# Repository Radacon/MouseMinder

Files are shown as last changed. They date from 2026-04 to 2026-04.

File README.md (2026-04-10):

# MouseMinder

MouseMinder is a small ATtiny10-based hardware project with a matching programming and test fixture. This repository combines the PCB design, fixture firmware, operator GUI, mechanical CAD exports, and simulation or validation data used to build and test the device.

## Repository Layout

- `codebase/`
  - Arduino Uno fixture firmware in `ardu_tiny_toaster.ino`
  - Base TPI programmer implementation in `tiny10_base_code.ino`
  - Operator desktop GUI in `gui.py`
  - Early or alternate device firmware work under `AtmelStudio/`
- `pcb_design/`
  - Main MouseMinder KiCad project files:
    - `MouseMinder.kicad_sch`
    - `MouseMinder.kicad_pcb`
    - `MouseMinder.kicad_pro`
  - Fixture or shield PCB design under `MouseMinder_Programmer_Shield/`
  - Archived KiCad backups under `MouseMinder-backups/`
  - Older release archives under `mouseminder_prev_versions/`
- `mechanical_design/`
  - Enclosure and trap body STEP exports under `trap_body/`
  - Accessory parts such as the battery isolator under `accessories/`
- `sim_and_test/`
  - Power profiling captures under `PowerProfilerData/`
  - Simulation exports under `Simulation/`

## Hardware Overview

The main board centers on an `ATtiny10-TS` and includes:

- A coin-cell battery holder
- A buzzer
- An LED indicator
- Two pushbuttons
- A discrete power or latching section around `Q1`

The repository also includes a separate programmer shield design and a fixture workflow for flashing and validating boards during bring-up or production.

## PCB Design Files

Primary electrical design assets live in `pcb_design/`:

- `MouseMinder.kicad_sch`
- `MouseMinder.kicad_pcb`
- `MouseMinder.kicad_pro`

Related hardware history is split out into:

- `pcb_design/MouseMinder_Programmer_Shield/` for the programming fixture PCB
- `pcb_design/MouseMinder-backups/` for KiCad backup archives
- `pcb_design/mouseminder_prev_versions/` for older packaged revisions

## Firmware And GUI

The programming and test fixture is built around an Arduino Uno and a Python desktop GUI.

Arduino-side files in `codebase/`:

- `ardu_tiny_toaster.ino`: fixture control firmware
- `tiny10_base_code.ino`: base TPI programming support for ATtiny4/5/9/10/20/40 devices

Desktop-side files in `codebase/`:

- `gui.py`: operator GUI for selecting firmware, discovering the fixture over serial, and running the programming loop
- `requirements.txt`: original behavior notes for the GUI and fixture

There is also an Atmel Studio project under `codebase/AtmelStudio/MouseMinder/` with a `main.c` firmware entry point and generated debug outputs.

## Fixture I/O Mapping

The current fixture firmware uses:

- `D10` -> `!RST`
- `D11/D12` -> `TPIDATA`
- `D13` -> `TPICLK`
- `A0` -> `BATT`
- `A1` -> `LATCHED`

The operator GUI is intended to:

- Auto-discover the Arduino fixture over available COM ports
- Show connection and pin-state information
- Let the operator select a `.hex` file
- Run the detect, program, verify, and test loop

## Mechanical Assets

Mechanical CAD exports are grouped under `mechanical_design/`:

- `trap_body/` contains enclosure and body STEP files, including lid and clip geometry
- `accessories/` contains supporting parts such as `Battery_Isolator_debossed.STEP`

## Simulation And Validation Data

Supporting measurement and simulation files live in `sim_and_test/`:

- `PowerProfilerData/` contains sleep-current or power measurement CSV files
- `Simulation/` contains scope and waveform export data from circuit simulation work

## Typical Workflow

1. Open the main hardware in `pcb_design/MouseMinder.kicad_sch` and `pcb_design/MouseMinder.kicad_pcb`.
2. Load the Arduino fixture firmware from `codebase/ardu_tiny_toaster.ino`.
3. Launch the operator GUI from `codebase/gui.py`.
4. Connect the programming fixture and target board.
5. Select a target `.hex` file and run the programming and test cycle.

## Running The GUI

Install the required Python package, then launch the GUI:

```powershell
pip install pyserial
python codebase\gui.py
```

The GUI depends on:

- `pyserial`
- Python standard library `tkinter`

## Fastest Entry Points

If you are picking up the project fresh, start with:

- `pcb_design/MouseMinder.kicad_sch`
- `pcb_design/MouseMinder.kicad_pcb`
- `codebase/ardu_tiny_toaster.ino`
- `codebase/gui.py`

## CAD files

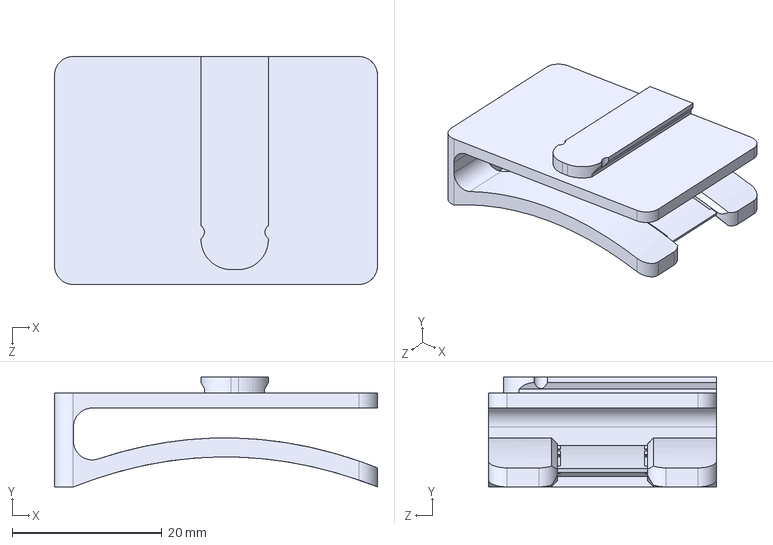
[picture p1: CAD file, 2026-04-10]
mechanical_design/accessories/clip.STEP
43.2 x 14.7 x 30.5 mm

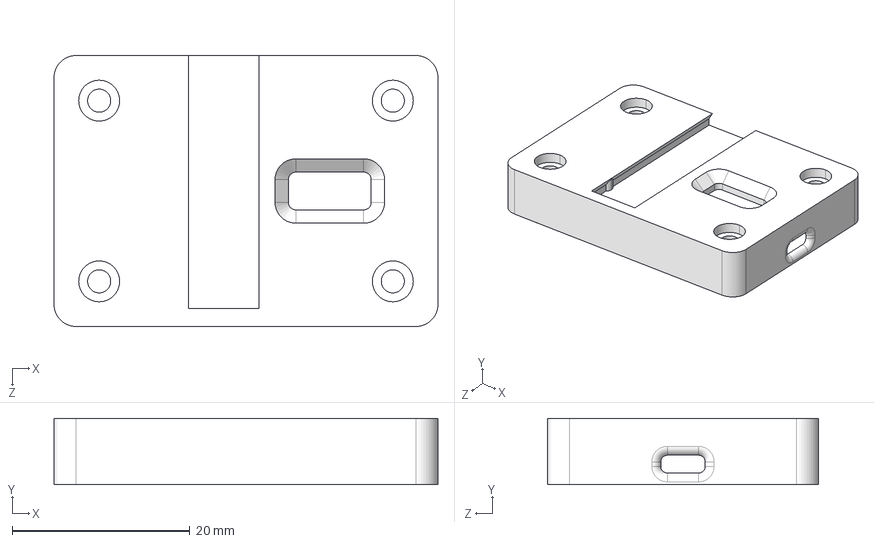
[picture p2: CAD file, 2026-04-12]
mechanical_design/trap_body/006_Trapside.step
43.2 x 7.44 x 30.5 mm

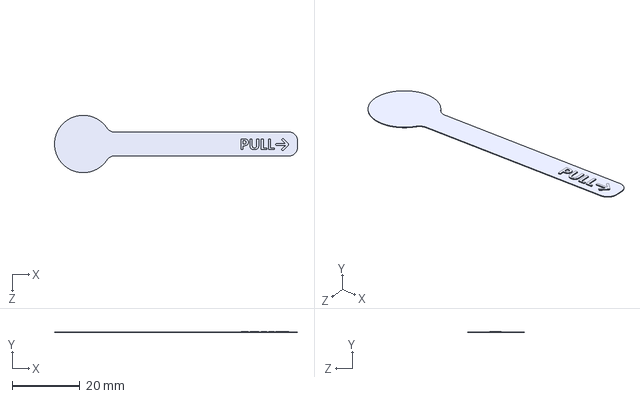
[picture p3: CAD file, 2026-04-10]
mechanical_design/accessories/Battery_Isolator_debossed.STEP
72.0 x 0.36 x 17.0 mm

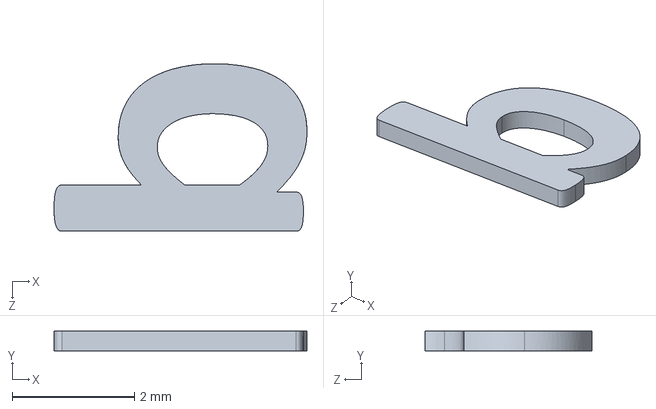
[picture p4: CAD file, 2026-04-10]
mechanical_design/trap_body/000_Boss-Extrude11[15].step
4.14 x 0.32 x 2.74 mm

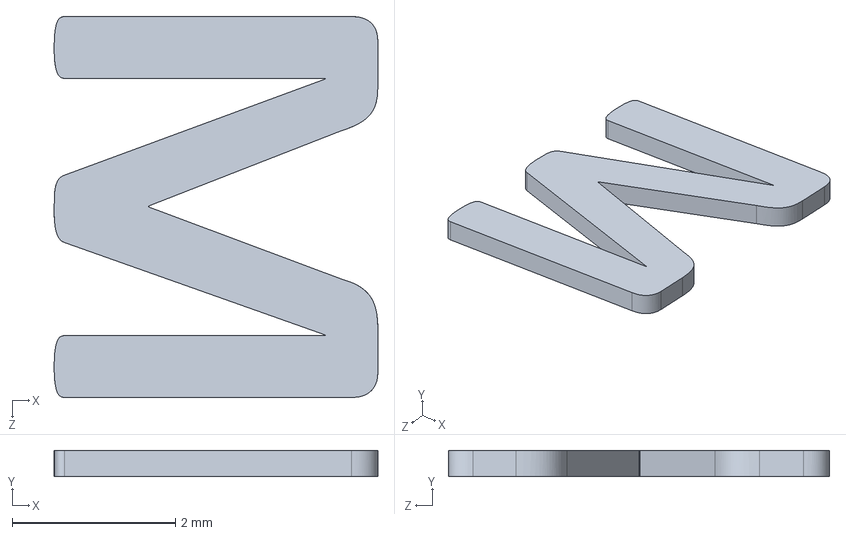
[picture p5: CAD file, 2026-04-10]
mechanical_design/trap_body/017_Boss-Extrude11[7].step
3.97 x 0.32 x 4.67 mm

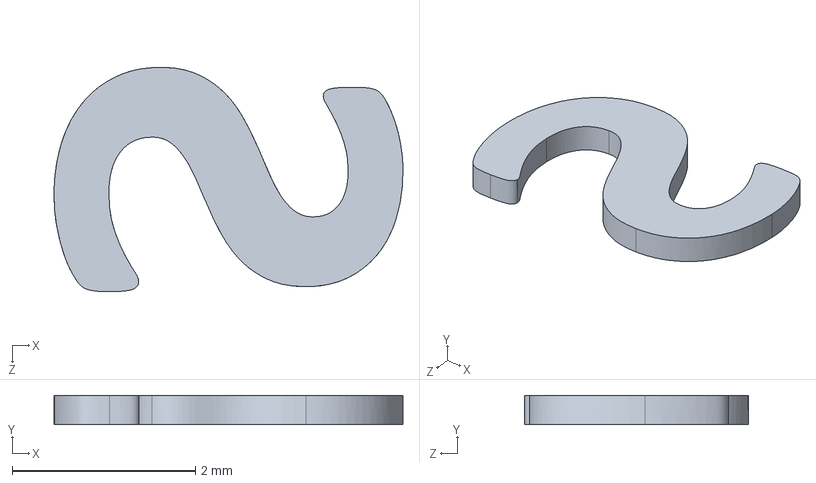
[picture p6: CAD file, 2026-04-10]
mechanical_design/trap_body/018_Boss-Extrude11[2].step
3.81 x 0.32 x 2.45 mm

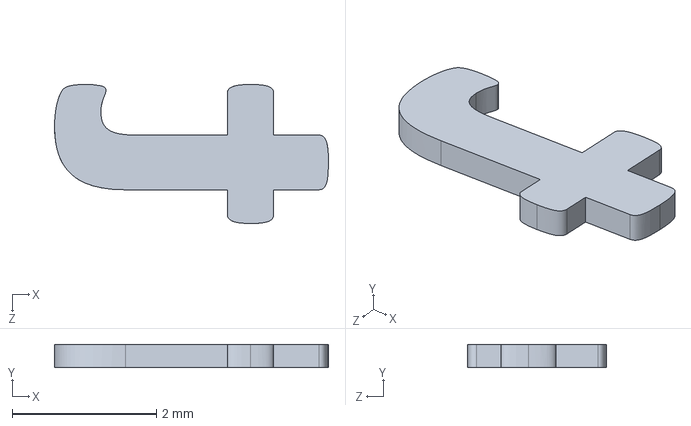
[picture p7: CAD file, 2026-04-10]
mechanical_design/trap_body/007_Boss-Extrude11[12].step
3.79 x 0.32 x 1.93 mm

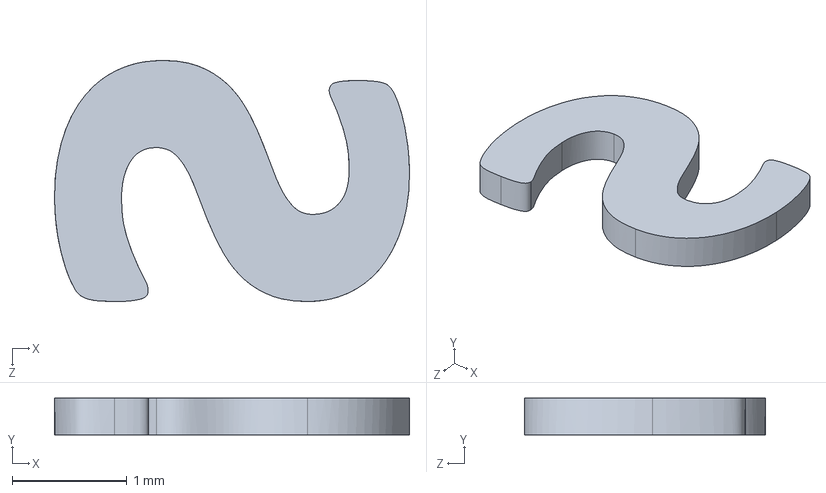
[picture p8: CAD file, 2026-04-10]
mechanical_design/trap_body/010_Boss-Extrude11[18].step
3.09 x 0.32 x 2.10 mm

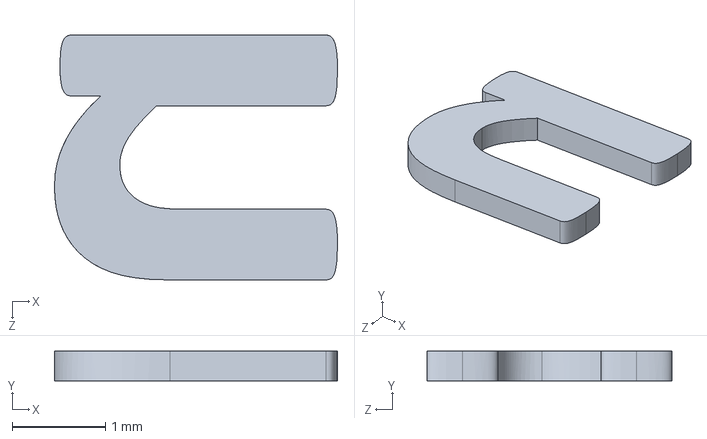
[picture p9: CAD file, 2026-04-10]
mechanical_design/trap_body/014_Boss-Extrude11[9].step
3.03 x 0.32 x 2.63 mm

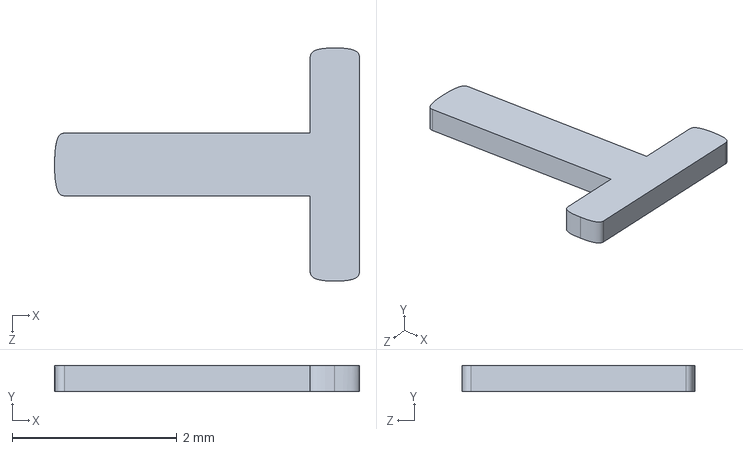
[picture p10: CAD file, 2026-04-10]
mechanical_design/trap_body/021_Boss-Extrude11[6].step
3.70 x 0.32 x 2.83 mm

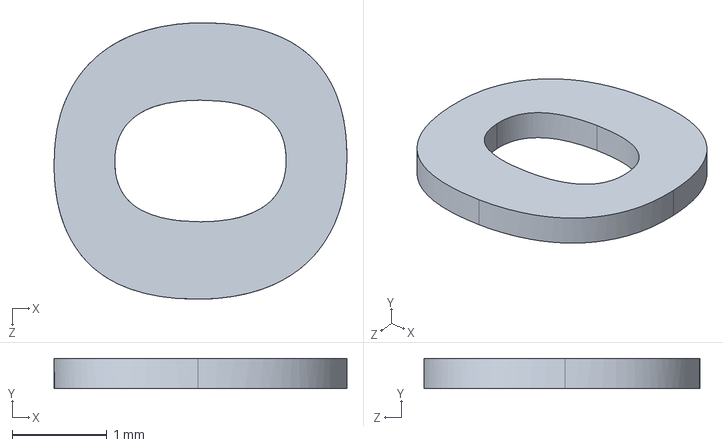
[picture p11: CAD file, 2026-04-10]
mechanical_design/trap_body/020_Boss-Extrude11[17].step
3.09 x 0.32 x 2.92 mm

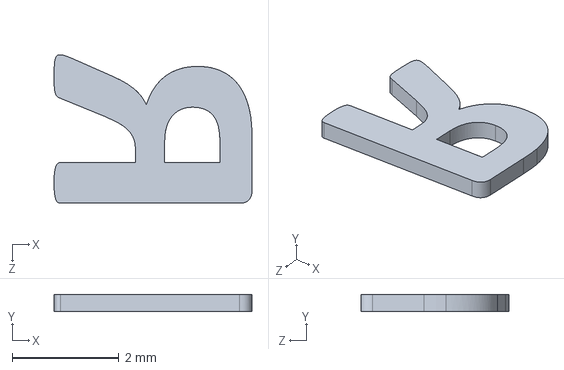
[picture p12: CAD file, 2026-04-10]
mechanical_design/trap_body/004_Boss-Extrude11[1].step
3.70 x 0.32 x 2.78 mm

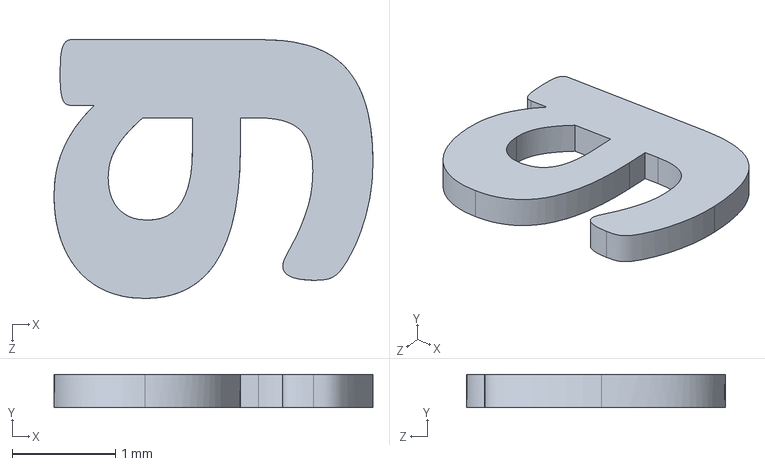
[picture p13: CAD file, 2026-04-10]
mechanical_design/trap_body/002_Boss-Extrude11[14].step
3.09 x 0.32 x 2.51 mm

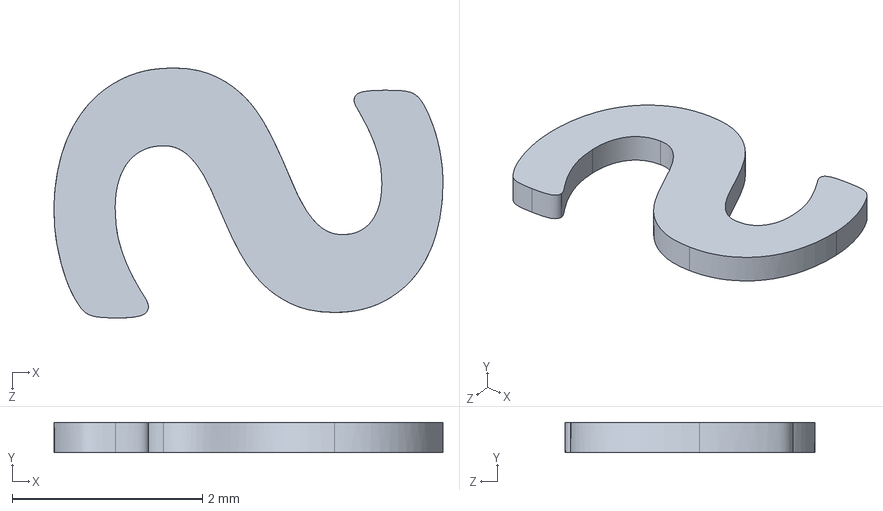
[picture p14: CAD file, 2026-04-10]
mechanical_design/trap_body/009_Boss-Extrude11[21].step
4.09 x 0.32 x 2.63 mm

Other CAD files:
mechanical_design/trap_body/005_Boss-Extrude11[13].step
mechanical_design/trap_body/003_Boss-Extrude11[8].step
mechanical_design/trap_body/011_Boss-Extrude11[16].step
mechanical_design/trap_body/022_Boss-Extrude11[5].step
mechanical_design/trap_body/001_Boss-Extrude11[4].step
mechanical_design/trap_body/008_Lid.step
mechanical_design/trap_body/012_Boss-Extrude11[10].step
mechanical_design/trap_body/013_Boss-Extrude11[11].step
mechanical_design/trap_body/015_Boss-Extrude11[3].step
mechanical_design/trap_body/016_Boss-Extrude11[20].step
mechanical_design/trap_body/019_Boss-Extrude11[19].step

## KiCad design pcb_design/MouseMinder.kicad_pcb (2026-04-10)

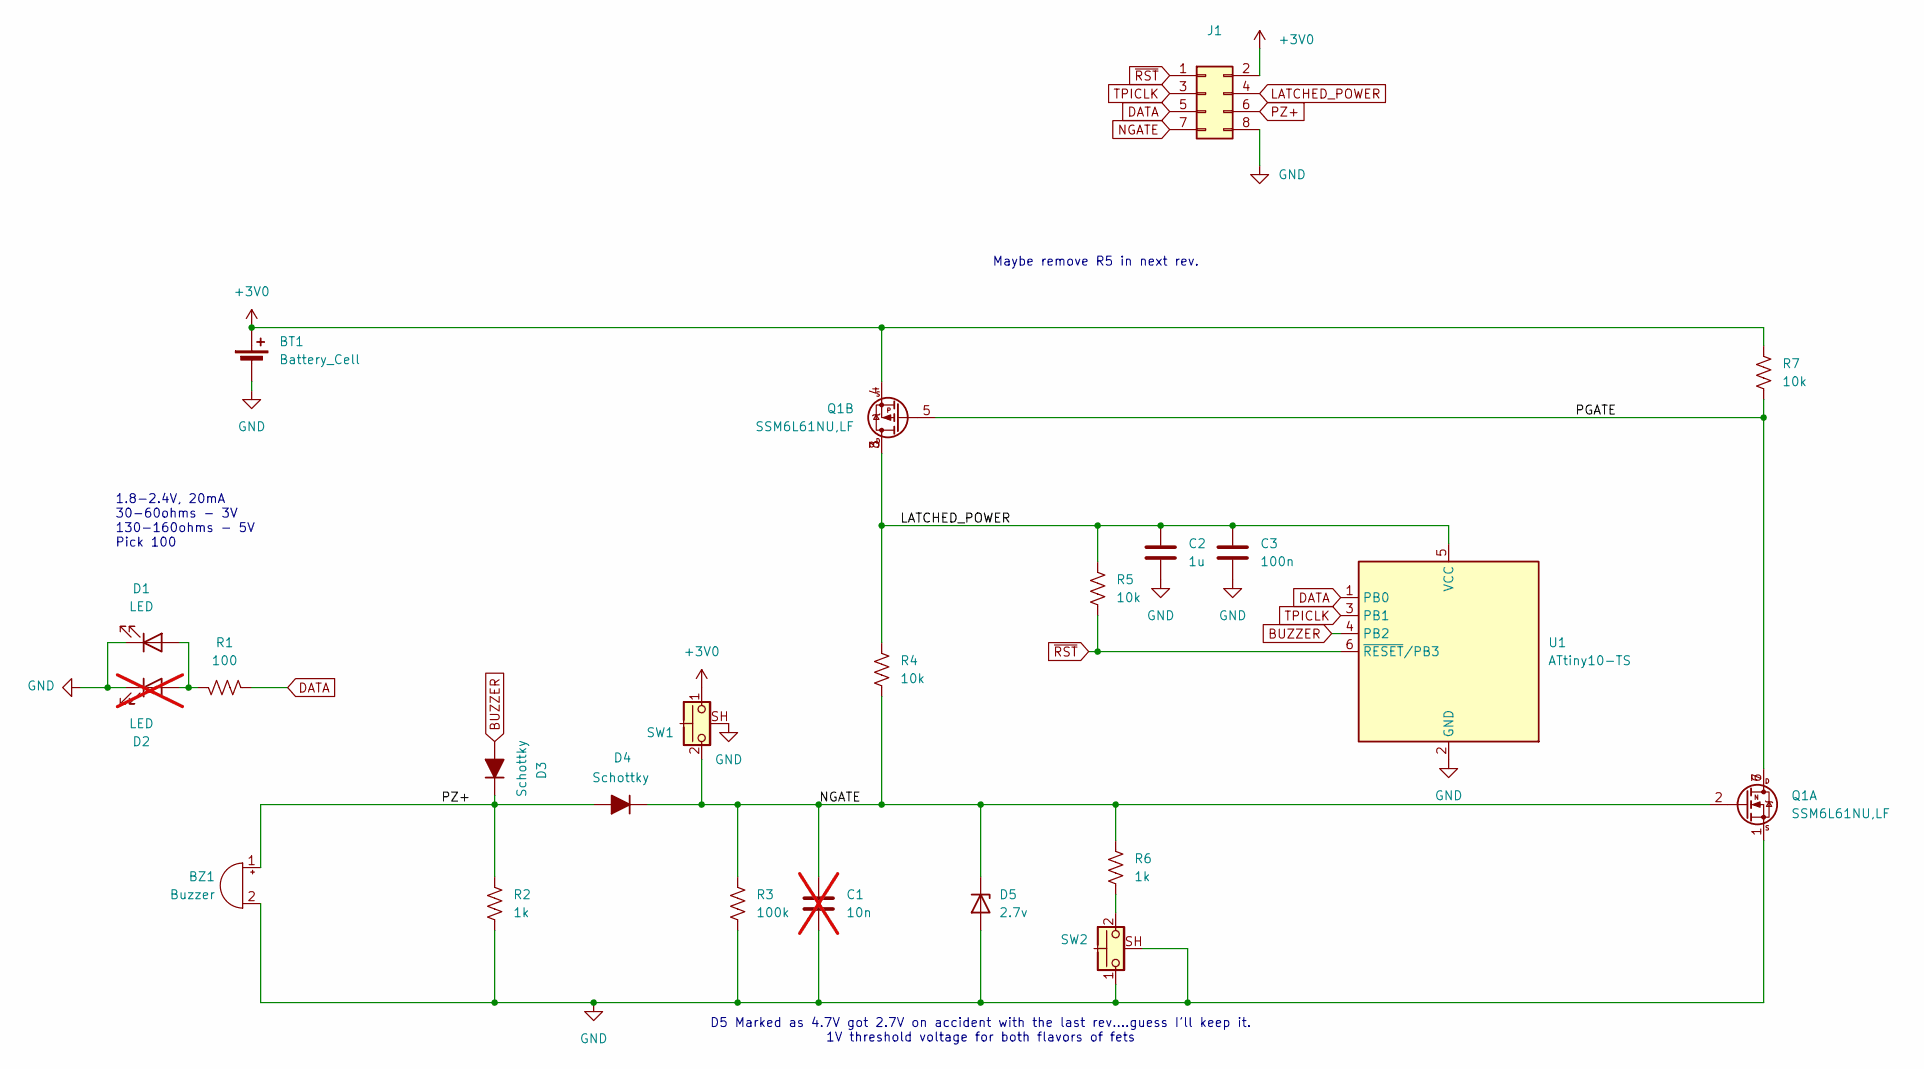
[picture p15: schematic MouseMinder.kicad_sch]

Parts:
BT1: Battery_Cell; MY-2032-08; MPN MY-2032-08; JLC_MPN C964831
BZ1: Buzzer; GSC1230YB-3V4000; MPN GSC1230YB-3V4000; JLC_MPN C255333
C1: 10n; C_0402_1005Metric; not fitted
C2: 1u; C_0402_1005Metric; MPN CL05A105KP5NNNC; JLC_MPN C14445
C3: 100n; C_0402_1005Metric; MPN 0402F104M500NT; JLC_MPN C1581
D1: LED; XL-2810UYC; MPN XL-2810UYC; JLC_MPN C3646949
D2: LED; LED_0805_2012Metric; MPN APTD2012LSURCK; JLC_MPN C5355441; not fitted
D3, D4: Schottky; D_0603_1608Metric; MPN CD0603-B0240R; JLC_MPN C3312582
D5: 2.7v; D_0603_1608Metric; MPN CZRU52C2V7-HF; JLC_MPN C2886070
J1: Conn_02x04_Odd_Even; PinHeader_2x04_P2.54mm_Vertical
Q1: SSM6L61NU,LF; SON65P200X200X80-8N; MPN DMC1229UFDB-7; JLC_MPN C443653
R1: 100; R_0402_1005Metric; MPN 0402WGF1000TCE; JLC_MPN C25076
R2, R6: 1k; R_0402_1005Metric; MPN 0402WGF1001TCE; JLC_MPN C11702
R3: 100k; R_0402_1005Metric; MPN 0402WGF1003TCE; JLC_MPN C25741
R4, R5, R7: 10k; R_0402_1005Metric; MPN RCA0210KJLF; JLC_MPN C22356213
SW1, SW2: SW_Push_Shielded; SW_Push_1P1T-SH_NO_CK_KMR2xxG; MPN KMR221GLFS; JLC_MPN C72443
U1: ATtiny10-TS; SOT-23-6; MPN ATTINY10-TSHR; JLC_MPN C128438

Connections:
+3V0: BT1.1 (+), J1.2, Q1.4 (SP), R7.1, SW1.1
/PGATE: Q1.5 (GP), Q1.6 (DN), Q1.7 (DN), R7.2
BUZZER: D3.2 (A), U1.4 (PB2)
DATA: J1.5, R1.1, U1.1 (PB0)
GND: BT1.2 (-), BZ1.2 (-), C1.2, C2.2, C3.2, D1.1 (K), D2.1 (K), D5.2 (A), J1.8, Q1.1 (SN), R2.2, R3.2, SW1.SH (B), SW2.1, SW2.SH (B), U1.2 (GND)
LATCHED_POWER: C2.1, C3.1, J1.4, Q1.3 (DP), Q1.8 (DP), R4.1, R5.1, U1.5 (VCC)
NGATE: C1.1, D4.1 (K), D5.1 (K), J1.7, Q1.2 (GN), R3.1, R4.2, R6.1, SW1.2
unnamed: D1.2 (A), D2.2 (A), R1.2
unnamed: R6.2, SW2.2
PZ+: BZ1.1 (+), D3.1 (K), D4.2 (A), J1.6, R2.1
TPICLK: J1.3, U1.3 (PB1)
~RST: J1.1, R5.2, U1.6 (~RESET/PB3)

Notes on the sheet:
1.8-2.4V, 20mA 30-60ohms - 3V 130-160ohms - 5V Pick 100
Maybe remove R5 in next rev.
D5 Marked as 4.7V got 2.7V on accident with the last rev....guess I'll keep it. 1V threshold voltage for both flavors of fets

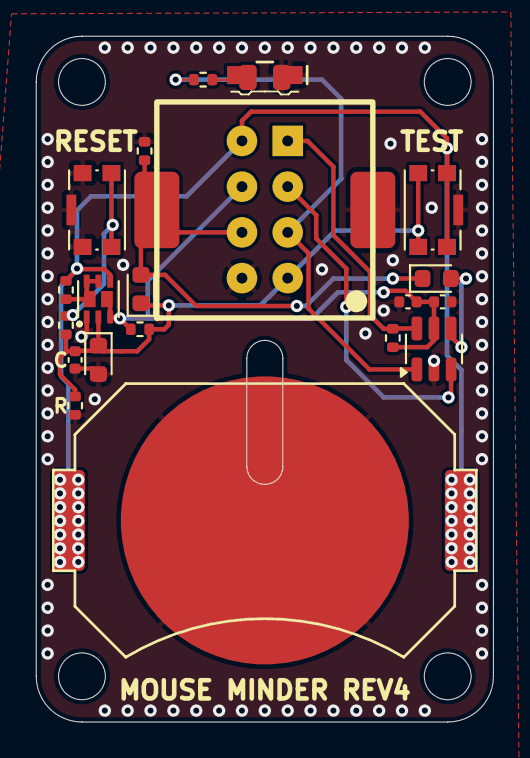
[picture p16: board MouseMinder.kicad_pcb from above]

Board: 2 copper layers, 25.4 x 38.1 mm, 22 parts (1 on the bottom side), 12 nets.

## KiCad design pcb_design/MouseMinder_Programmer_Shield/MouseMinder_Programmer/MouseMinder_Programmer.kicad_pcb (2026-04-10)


Board: 2 copper layers, 68.6 x 53.3 mm, 8 parts (0 on the bottom side), 3 nets, no tracks yet.

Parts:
J1: Power; PinSocket_1x08_P2.54mm_Vertical
J2: Digital/PWM; PinSocket_1x10_P2.54mm_Vertical
J3: Analog; PinSocket_1x06_P2.54mm_Vertical
J4: Digital/PWM; PinSocket_1x08_P2.54mm_Vertical
MH1, MH2, MH3, MH4: MountingHole_3.2mm

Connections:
/SCL/A5: J2.1, J3.6
/SDA/A4: J2.2, J3.5
GND: J1.6, J1.7, J2.4

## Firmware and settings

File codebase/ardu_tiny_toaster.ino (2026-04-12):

#include <SPI.h>
#include "pins_arduino.h"

#define SLD    0x20
#define SLDp   0x24
#define SSTp   0x64
#define SSTPRH 0x69
#define SSTPRL 0x68
#define SKEY   0xE0
#define NVM_PROGRAM_ENABLE 0x1289AB45CDD888FFULL

#define NVMCMD 0x33
#define NVMCSR 0x32
#define NVM_NOP 0x00
#define NVM_CHIP_ERASE 0x10
#define NVM_WORD_WRITE 0x1D

#define PIN_RESET 10
#define PIN_TPIDATA_MOSI 11
#define PIN_TPIDATA_MISO 12
#define PIN_TPICLK 13
#define PIN_BATT A0
#define PIN_LATCHED A1

#define Tiny4_5 10
#define Tiny9 1
#define Tiny10 1
#define Tiny20 2
#define Tiny40 4

#define TimeOut 1
#define HexError 2
#define TooLarge 3
#define MAX_VERIFY_FLASH_BYTES 1024
#define BATT_FAIL_THRESHOLD_MV 2000
#define SERIAL_BAUDRATE 115200

enum ToasterState {
  STATE_WAIT_GUI,
  STATE_WAIT_TEST_BUTTON,
  STATE_WAIT_RESET_BUTTON,
  STATE_WAIT_TEST_CONFIRM,
  STATE_SCAN_DEVICE,
  STATE_WAIT_HEX,
  STATE_WAIT_BATT_CLEAR
};

enum PinRoleMode {
  ROLE_INPUT,
  ROLE_OUTPUT,
  ROLE_ADC
};

unsigned short adrs = 0x0000;
uint8_t data[16];
uint8_t expectedImage[MAX_VERIFY_FLASH_BYTES];
unsigned int progSize = 0;
unsigned int expectedImageSize = 0;
bool expectedImageValid = false;

int timeout;
uint8_t b, b1, b2, b3;
char type = 0;

ToasterState state = STATE_WAIT_GUI;
bool guiConnected = false;
bool hexRequested = false;
bool actionRequested = false;
bool programPrepared = false;
bool lastDeviceValid = false;
bool tpiTimedOut = false;
size_t serialLineIndex = 0;
unsigned long lastHelloAt = 0;
unsigned long lastScanAt = 0;
unsigned long lastPinReportAt = 0;
unsigned long battClearSince = 0;
unsigned long latchedHighSince = 0;
unsigned long latchedLowSince = 0;
unsigned long stateChangedAt = 0;

PinRoleMode battMode = ROLE_OUTPUT;
PinRoleMode latchedMode = ROLE_OUTPUT;
int battOutputValue = LOW;
int latchedOutputValue = LOW;

uint8_t lastId1 = 0;
uint8_t lastId2 = 0;
uint8_t lastId3 = 0;

void setState(ToasterState nextState, const __FlashStringHelper *message);
void emitHello();
void emitLog(const __FlashStringHelper *message);
void emitResult(const __FlashStringHelper *code, long detail = -1);
void emitDevice(bool valid);
void emitPins();
void emitPinBatt();
void emitPinLatched();
const __FlashStringHelper *stateName(ToasterState value);
const __FlashStringHelper *deviceNameFromId(uint8_t id1, uint8_t id2, uint8_t id3);
void configureForScan();
void configureForWaitButton();
void resetForNextDevice();
void emitRawDeviceId();
void setProgrammingPinsHighImpedance();
void setBattOutput(int value);
void setBattAdc();
void setLatchedOutput(int value);
void setLatchedAdc();
int readBattMillivolts();
int readLatchedMillivolts();
int sampleBattAverageMillivolts(unsigned long durationMs);
bool latchedIsHigh();
bool latchedIsStableHigh();
void resetSerialLineReader();
bool readSerialLine(char *buffer, size_t length);
void handleCommand(const char *line);
void processStateMachine();
void processScanDevice();
void processWaitHex();
bool runProgrammingCycle();
bool beginProgrammingSession();
bool runClearCycle();
bool runMetadataReadCycle();
void completeClearRequest();
void completeMetadataReadRequest();
bool start_tpi();
void finish();
bool readDeviceIdentity(uint8_t &id1, uint8_t &id2, uint8_t &id3);
bool detectConnectedDevice();
boolean writeProgramFromSerial();
bool waitForNvmReady(unsigned long timeoutMs);
unsigned int flashByteLength();
bool supportsFlashVerify();
void resetExpectedImage();
bool storeExpectedByte(unsigned int address, uint8_t value);
bool dumpAndVerifyBlankFlash();
bool verifyWrittenFlash();
void dumpFlashWindow(unsigned int flashBytes);
bool readFlashByteAt(unsigned int flashOffset, uint8_t &value);
bool readFlashPage(unsigned int flashOffset, uint8_t *buffer, uint8_t count);
bool pageMatchesMetadata(const uint8_t *buffer, const char *text);
void emitMetadataField(const __FlashStringHelper *key, const uint8_t *buffer, uint8_t count);
bool latchedIsLow();
bool latchedIsStableLow();
int readHexChar();
void discardToLineEnd();
bool eraseChip();
void ERROR_data(char i);
void tpi_send_byte(uint8_t dataByte);
uint8_t tpi_receive_byte(void);
void send_skey(uint64_t nvm_key);
void setPointer(unsigned short address);
void writeIO(uint8_t address, uint8_t value);
uint8_t readIO(uint8_t address);
void writeCSS(uint8_t address, uint8_t value);
uint8_t readCSS(uint8_t address);
uint8_t byteval(char c1, char c2);
void outHex(unsigned int n, char l);

void setup() {
  Serial.begin(SERIAL_BAUDRATE);
  timeout = 20000;
  setProgrammingPinsHighImpedance();
  configureForScan();
  setState(STATE_WAIT_GUI, F("WAITING_FOR_GUI"));
}

void loop() {
  if (!guiConnected && millis() - lastHelloAt >= 500) {
    emitHello();
    lastHelloAt = millis();
  }

  if (state == STATE_WAIT_HEX) {
    processWaitHex();
  } else {
    char line[96];
    if (readSerialLine(line, sizeof(line))) {
      handleCommand(line);
    }
  }

  if (guiConnected) {
    processStateMachine();
  }

  if (state != STATE_WAIT_HEX && millis() - lastPinReportAt >= 250) {
    emitPins();
    lastPinReportAt = millis();
  }
}

void setState(ToasterState nextState, const __FlashStringHelper *message) {
  ToasterState previous = state;
  state = nextState;
  resetSerialLineReader();
  stateChangedAt = millis();
  Serial.print(F("LOG STATE_"));
  Serial.print(stateName(previous));
  Serial.print(F("_TO_"));
  Serial.println(stateName(nextState));
  Serial.print(F("STATUS "));
  Serial.print(stateName(nextState));
  Serial.print(F(" "));
  Serial.println(message);
}

const __FlashStringHelper *stateName(ToasterState value) {
  switch (value) {
    case STATE_WAIT_GUI: return F("WAIT_GUI");
    case STATE_WAIT_TEST_BUTTON: return F("WAIT_TEST_BUTTON");
    case STATE_WAIT_RESET_BUTTON: return F("WAIT_RESET_BUTTON");
    case STATE_WAIT_TEST_CONFIRM: return F("WAIT_TEST_CONFIRM");
    case STATE_SCAN_DEVICE: return F("SCAN_DEVICE");
    case STATE_WAIT_HEX: return F("WAIT_HEX");
    case STATE_WAIT_BATT_CLEAR: return F("WAIT_BATT_CLEAR");
    default: return F("UNKNOWN");
  }
}

void emitHello() {
  Serial.println(F("HELLO ARDUINO_TOASTER"));
}

void emitLog(const __FlashStringHelper *message) {
  Serial.print(F("LOG "));
  Serial.println(message);
}

void emitResult(const __FlashStringHelper *code, long detail) {
  Serial.print(F("RESULT "));
  Serial.print(code);
  if (detail >= 0) {
    Serial.print(F(" "));
    Serial.println(detail);
    return;
  }
  Serial.println();
}

const __FlashStringHelper *deviceNameFromId(uint8_t id1, uint8_t id2, uint8_t id3) {
  if (id1 == 0x1E && id2 == 0x8F && id3 == 0x0A) {
    return F("ATtiny4");
  }
  if (id1 == 0x1E && id2 == 0x8F && id3 == 0x09) {
    return F("ATtiny5");
  }
  if (id1 == 0x1E && id2 == 0x90 && id3 == 0x08) {
    return F("ATtiny9");
  }
  if (id1 == 0x1E && id2 == 0x90 && id3 == 0x03) {
    return F("ATtiny10");
  }
  if (id1 == 0x1E && id2 == 0x91 && id3 == 0x0F) {
    return F("ATtiny20");
  }
  if (id1 == 0x1E && id2 == 0x92 && id3 == 0x0E) {
    return F("ATtiny40");
  }
  return F("UNKNOWN");
}

void emitDevice(bool valid) {
  Serial.print(F("DEVICE "));
  Serial.print(valid ? F("VALID ") : F("INVALID "));
  Serial.print(valid ? deviceNameFromId(lastId1, lastId2, lastId3) : F("UNKNOWN"));
  Serial.print(F(" "));
  outHex(lastId1, 2);
  outHex(lastId2, 2);
  outHex(lastId3, 2);
  Serial.println();
}

void emitRawDeviceId() {
  Serial.print(F("LOG RAW_ID_"));
  outHex(lastId1, 2);
  Serial.print(F("_"));
  outHex(lastId2, 2);
  Serial.print(F("_"));
  outHex(lastId3, 2);
  Serial.println();
}

void emitPins() {
  emitPinBatt();
  emitPinLatched();
}

void emitPinBatt() {
  Serial.print(F("PIN BATT "));
  if (battMode == ROLE_OUTPUT) {
    Serial.print(F("OUT "));
    Serial.println(battOutputValue == HIGH ? F("HIGH") : F("LOW"));
    return;
  }
  if (battMode == ROLE_ADC) {
    Serial.print(F("ADC "));
    Serial.print(readBattMillivolts());
    Serial.println(F("mV"));
    return;
  }
  Serial.print(F("IN "));
  Serial.println(digitalRead(PIN_BATT) == HIGH ? F("HIGH") : F("LOW"));
}

void emitPinLatched() {
  Serial.print(F("PIN LATCHED "));
  if (latchedMode == ROLE_OUTPUT) {
    Serial.print(F("OUT "));
    Serial.println(latchedOutputValue == HIGH ? F("HIGH") : F("LOW"));
    return;
  }
  if (latchedMode == ROLE_ADC) {
    Serial.print(F("ADC "));
    Serial.print(readLatchedMillivolts());
    Serial.println(F("mV"));
    return;
  }
  Serial.print(F("IN "));
  Serial.println(latchedIsHigh() ? F("HIGH") : F("LOW"));
}

void configureForScan() {
  setProgrammingPinsHighImpedance();
  setBattOutput(HIGH);
  setLatchedAdc();
  battClearSince = 0;
}

void configureForWaitButton() {
  configureForScan();
}

void resetForNextDevice() {
  hexRequested = false;
  actionRequested = false;
  programPrepared = false;
  resetSerialLineReader();
  latchedHighSince = 0;
  latchedLowSince = 0;
  battClearSince = 0;
  lastDeviceValid = false;
  emitDevice(false);
  configureForWaitButton();
  setState(STATE_WAIT_TEST_BUTTON, F("PRESS_TEST"));
}

void setProgrammingPinsHighImpedance() {
  SPI.end();

  pinMode(PIN_RESET, INPUT);
  digitalWrite(PIN_RESET, LOW);

  pinMode(PIN_TPIDATA_MOSI, INPUT);
  digitalWrite(PIN_TPIDATA_MOSI, LOW);

  pinMode(PIN_TPIDATA_MISO, INPUT);
  digitalWrite(PIN_TPIDATA_MISO, LOW);

  pinMode(PIN_TPICLK, INPUT);
  digitalWrite(PIN_TPICLK, LOW);
}

void setBattOutput(int value) {
  pinMode(PIN_BATT, OUTPUT);
  digitalWrite(PIN_BATT, value);
  battMode = ROLE_OUTPUT;
  battOutputValue = value;
}

void setBattAdc() {
  pinMode(PIN_BATT, INPUT);
  battMode = ROLE_ADC;
}

void setLatchedOutput(int value) {
  pinMode(PIN_LATCHED, OUTPUT);
  digitalWrite(PIN_LATCHED, value);
  latchedMode = ROLE_OUTPUT;
  latchedOutputValue = value;
}

void setLatchedAdc() {
  pinMode(PIN_LATCHED, INPUT);
  latchedMode = ROLE_ADC;
}

int readBattMillivolts() {
  long sample = analogRead(PIN_BATT);
  return (int)((sample * 5000L) / 1023L);
}

int readLatchedMillivolts() {
  long sample = analogRead(PIN_LATCHED);
  return (int)((sample * 5000L) / 1023L);
}

int sampleBattAverageMillivolts(unsigned long durationMs) {
  unsigned long started = millis();
  unsigned long total = 0;
  unsigned int count = 0;
  while (millis() - started < durationMs) {
    total += (unsigned long)readBattMillivolts();
    ++count;
    delay(10);
  }
  if (count == 0) {
    return readBattMillivolts();
  }
  return (int)(total / count);
}

bool latchedIsHigh() {
  return readLatchedMillivolts() >= 3000;
}

bool latchedIsLow() {
  return readLatchedMillivolts() <= 1000;
}

bool latchedIsStableHigh() {
  if (latchedIsHigh()) {
    if (latchedHighSince == 0) {
      latchedHighSince = millis();
    }
    latchedLowSince = 0;
    return (millis() - latchedHighSince) >= 500;
  }

  latchedHighSince = 0;
  return false;
}

bool latchedIsStableLow() {
  if (latchedIsLow()) {
    if (latchedLowSince == 0) {
      latchedLowSince = millis();
    }
    latchedHighSince = 0;
    return (millis() - latchedLowSince) >= 500;
  }

  latchedLowSince = 0;
  return false;
}

void resetSerialLineReader() {
  serialLineIndex = 0;
}

bool readSerialLine(char *buffer, size_t length) {
  while (Serial.available() > 0) {
    char c = (char)Serial.read();
    if (c == '\r') {
      continue;
    }
    if (c == '\n') {
      if (serialLineIndex == 0) {
        continue;
      }
      buffer[serialLineIndex] = '\0';
      serialLineIndex = 0;
      return true;
    }
    if (serialLineIndex < length - 1) {
      buffer[serialLineIndex++] = c;
    }
  }
  return false;
}

void handleCommand(const char *line) {
  Serial.print(F("LOG CMD_RX_"));
  Serial.print(line);
  Serial.print(F("_IN_"));
  Serial.println(stateName(state));

  if (strcmp(line, "GUI_HELLO") == 0) {
    guiConnected = true;
    Serial.println(F("ACK GUI"));
    resetForNextDevice();
    return;
  }

  if (strcmp(line, "ABORT") == 0 && state == STATE_WAIT_HEX) {
    programPrepared = false;
    resetForNextDevice();
    return;
  }

  if (strcmp(line, "RESET_LOOP") == 0 && guiConnected) {
    programPrepared = false;
    emitLog(F("RESET_LOOP_RECEIVED"));
    resetForNextDevice();
    return;
  }

    if (strcmp(line, "CLEAR") == 0 && state == STATE_WAIT_HEX) {
      Serial.println(F("ACK CLEAR"));
      completeClearRequest();
      return;
    }
  
    if (strcmp(line, "READ_METADATA") == 0 && state == STATE_WAIT_HEX) {
      Serial.println(F("ACK READ_METADATA"));
      completeMetadataReadRequest();
      return;
    }
}

void processStateMachine() {
  switch (state) {
    case STATE_WAIT_GUI:
      break;
    case STATE_WAIT_TEST_BUTTON:
      if (latchedIsStableHigh()) {
        latchedHighSince = 0;
        setState(STATE_WAIT_RESET_BUTTON, F("PRESS_RESET"));
      } else if (millis() - stateChangedAt >= 2000) {
        resetForNextDevice();
      }
      break;
    case STATE_WAIT_RESET_BUTTON:
      if (latchedIsStableLow()) {
        latchedLowSince = 0;
        setState(STATE_WAIT_TEST_CONFIRM, F("PRESS_TEST_AGAIN"));
      }
      break;
    case STATE_WAIT_TEST_CONFIRM:
      if (latchedIsStableHigh()) {
        latchedHighSince = 0;
        setState(STATE_SCAN_DEVICE, F("READING_DEVICE_ID"));
      } else if (millis() - stateChangedAt >= 2000) {
        resetForNextDevice();
      }
      break;
    case STATE_SCAN_DEVICE:
      processScanDevice();
      break;
    case STATE_WAIT_HEX:
      break;
    case STATE_WAIT_BATT_CLEAR: {
      int battMv = readBattMillivolts();
      if (battMv <= 500) {
        if (battClearSince == 0) {
          battClearSince = millis();
        } else if (millis() - battClearSince >= 500) {
          resetForNextDevice();
        }
      } else {
        battClearSince = 0;
      }
      break;
    }
    default:
      break;
  }
}

void processScanDevice() {
  Serial.print(F("LOG SCAN_LATCHED_MV_"));
  Serial.println(readLatchedMillivolts());
  if (!latchedIsHigh()) {
    latchedHighSince = 0;
    latchedLowSince = 0;
    if (lastDeviceValid) {
      emitDevice(false);
      lastDeviceValid = false;
    }
    setState(STATE_WAIT_TEST_CONFIRM, F("PRESS_TEST_AGAIN"));
    return;
  }

  if (millis() - lastScanAt < 500) {
    return;
  }
  lastScanAt = millis();

    bool valid = detectConnectedDevice();
  Serial.print(F("LOG SCAN_DEVICE_VALID_"));
  Serial.println(valid ? F("YES") : F("NO"));
  if (valid != lastDeviceValid) {
    emitDevice(valid);
    lastDeviceValid = valid;
  }

    if (valid) {
      hexRequested = false;
      actionRequested = false;
      setState(STATE_WAIT_HEX, F("SEND_HEX_FILE"));
    }
  }
  
  void processWaitHex() {
  if (!actionRequested) {
    Serial.println(F("REQUEST ACTION"));
    actionRequested = true;
  }

  while (Serial.available() > 0) {
    if (hexRequested) {
      int next = Serial.peek();
      if (next == '\r' || next == '\n') {
        Serial.read();
        continue;
      }
      if (next == ':') {
        bool success = runProgrammingCycle();
        bool batteryPass = false;
        battClearSince = 0;
        if (success) {
          emitResult(F("PROGRAM_OK"));
        } else {
          emitResult(F("PROGRAM_FAIL"));
        }

        setBattOutput(LOW);
        setLatchedOutput(LOW);
        delay(50);
        setBattAdc();
        setLatchedAdc();
        int battMv = sampleBattAverageMillivolts(100);
        if (battMv <= BATT_FAIL_THRESHOLD_MV) {
          batteryPass = true;
          emitResult(F("BATTERY_OK"), battMv);
        } else {
          emitResult(F("BATTERY_FAIL"), battMv);
        }

        setState(STATE_WAIT_BATT_CLEAR, F("REMOVE_DEVICE"));
        hexRequested = false;
        actionRequested = false;
        lastDeviceValid = success && batteryPass;
        return;
      }
    }

    char line[96];
    if (!readSerialLine(line, sizeof(line))) {
      return;
    }
    Serial.print(F("LOG WAIT_HEX_RX_"));
    Serial.println(line);
    if (strcmp(line, "PROGRAM") == 0) {
      if (!beginProgrammingSession()) {
        battClearSince = 0;
        emitResult(F("PROGRAM_FAIL"));
        emitResult(F("BATTERY_OK"), 0);
        setState(STATE_WAIT_BATT_CLEAR, F("REMOVE_DEVICE"));
        hexRequested = false;
        actionRequested = false;
        lastDeviceValid = false;
        return;
      }
      Serial.println(F("ACK PROGRAM"));
      Serial.println(F("REQUEST HEX"));
      hexRequested = true;
      return;
    }
    if (strcmp(line, "CLEAR") == 0) {
      Serial.println(F("ACK CLEAR"));
      completeClearRequest();
      return;
    }
    if (strcmp(line, "READ_METADATA") == 0) {
      Serial.println(F("ACK READ_METADATA"));
      completeMetadataReadRequest();
      return;
    }
    handleCommand(line);
  }
}

void completeClearRequest() {
  emitLog(F("CLEAR_RECEIVED"));
  bool success = runClearCycle();
  battClearSince = 0;
  if (success) {
    emitResult(F("CLEAR_OK"));
  } else {
    emitResult(F("CLEAR_FAIL"));
  }

  setState(STATE_WAIT_BATT_CLEAR, F("REMOVE_DEVICE"));
  hexRequested = false;
  actionRequested = false;
  lastDeviceValid = success;
}

void completeMetadataReadRequest() {
  emitLog(F("READ_METADATA_RECEIVED"));
  bool success = runMetadataReadCycle();
  battClearSince = 0;
  if (success) {
    emitResult(F("METADATA_OK"));
  } else {
    emitResult(F("METADATA_FAIL"));
  }

  setState(STATE_WAIT_BATT_CLEAR, F("REMOVE_DEVICE"));
  hexRequested = false;
  actionRequested = false;
  lastDeviceValid = success;
}

bool runProgrammingCycle() {
  emitLog(F("PROGRAMMING"));
  if (!programPrepared) {
    emitLog(F("PROGRAM_NOT_PREPARED"));
    return false;
  }

  if (!start_tpi()) {
    finish();
    emitLog(F("TPI_START_FAILED"));
    return false;
  }

  if (!readDeviceIdentity(lastId1, lastId2, lastId3)) {
    finish();
    emitLog(F("DEVICE_ID_READ_FAILED"));
    return false;
  }

  bool valid = (type != 0);
  emitDevice(valid);
  if (!valid) {
    finish();
    emitLog(F("INVALID_DEVICE"));
    return false;
  }

  bool programmed = writeProgramFromSerial();
  bool verified = false;
  if (programmed) {
    verified = verifyWrittenFlash();
    if (!verified) {
      emitLog(F("VERIFY_FAILED"));
    }
  }
  finish();
  programPrepared = false;
  return programmed && verified;
}

bool beginProgrammingSession() {
  programPrepared = false;

  if (!start_tpi()) {
    finish();
    emitLog(F("TPI_START_FAILED"));
    return false;
  }

  if (!readDeviceIdentity(lastId1, lastId2, lastId3)) {
    finish();
    emitLog(F("DEVICE_ID_READ_FAILED"));
    return false;
  }

  bool valid = (type != 0);
  emitDevice(valid);
  if (!valid) {
    finish();
    emitLog(F("INVALID_DEVICE"));
    return false;
  }

  if (!eraseChip()) {
    finish();
    emitLog(F("ERASE_FAILED"));
    return false;
  }

  finish();
  programPrepared = true;
  return true;
}

bool runClearCycle() {
  emitLog(F("CLEARING_MEMORY"));
  if (!start_tpi()) {
    finish();
    emitLog(F("TPI_START_FAILED"));
    return false;
  }

  emitLog(F("CLEAR_TPI_STARTED"));

  if (!eraseChip()) {
    finish();
    emitLog(F("ERASE_FAILED"));
    return false;
  }
  if (!dumpAndVerifyBlankFlash()) {
    finish();
    emitLog(F("BLANK_VERIFY_FAILED"));
    return false;
  }
  emitLog(F("ERASE_COMPLETE"));
  finish();
  return true;
}

bool runMetadataReadCycle() {
  if (!start_tpi()) {
    finish();
    emitLog(F("TPI_START_FAILED"));
    return false;
  }

  if (!readDeviceIdentity(lastId1, lastId2, lastId3)) {
    finish();
    emitLog(F("DEVICE_ID_READ_FAILED"));
    return false;
  }

  bool valid = (type != 0);
  emitDevice(valid);
  if (!valid) {
    finish();
    emitLog(F("INVALID_DEVICE"));
    return false;
  }

  const char verse[] = "Luke 19:39-40";
  uint8_t page[16];
  bool found = false;
  unsigned int verseOffset = 0;

  for (unsigned int offset = 0; offset + 16 <= flashByteLength(); offset += 16) {
    if (!readFlashPage(offset, page, 16)) {
      finish();
      emitLog(F("METADATA_READ_FAILED"));
      return false;
    }
    if (pageMatchesMetadata(page, verse)) {
      verseOffset = offset;
      found = true;
      break;
    }
  }

  if (!found || verseOffset < 32) {
    finish();
    emitLog(F("METADATA_NOT_FOUND"));
    emitResult(F("METADATA_NONE"));
    return false;
  }

  if (!readFlashPage(verseOffset - 32, page, 16)) {
    finish();
    emitLog(F("METADATA_READ_FAILED"));
    return false;
  }
  emitMetadataField(F("UNIX"), page, 16);

  if (!readFlashPage(verseOffset - 16, page, 16)) {
    finish();
    emitLog(F("METADATA_READ_FAILED"));
    return false;
  }
  emitMetadataField(F("GIT"), page, 16);

  if (!readFlashPage(verseOffset, page, 16)) {
    finish();
    emitLog(F("METADATA_READ_FAILED"));
    return false;
  }
  emitMetadataField(F("VERSE"), page, 16);

  finish();
  return true;
}

bool detectConnectedDevice() {
  if (!start_tpi()) {
    emitLog(F("SCAN_TPI_START_FAILED"));
    type = 0;
    finish();
    return false;
  }
  emitLog(F("SCAN_TPI_START_OK"));

  bool valid = readDeviceIdentity(lastId1, lastId2, lastId3);
  emitRawDeviceId();
  finish();
  return valid;
}

bool start_tpi() {
  tpiTimedOut = false;
  pinMode(PIN_RESET, OUTPUT);
  digitalWrite(PIN_RESET, HIGH);
  SPI.begin();
  SPI.setBitOrder(LSBFIRST);
  SPI.setDataMode(SPI_MODE0);
  SPI.setClockDivider(SPI_CLOCK_DIV32);

  digitalWrite(PIN_RESET, LOW);
  delay(1);

  SPI.transfer(0xff);
  SPI.transfer(0xff);
  SPI.transfer(0xff);

  writeCSS(0x02, 0x04);
  send_skey(NVM_PROGRAM_ENABLE);

  unsigned long started = millis();
  while ((readCSS(0x00) & 0x02) < 1) {
    if (tpiTimedOut) {
      emitLog(F("START_TPI_TIMEOUT"));
      SPI.end();
      digitalWrite(PIN_RESET, HIGH);
      return false;
    }
    if (millis() - started > 50) {
      emitLog(F("START_TPI_READY_TIMEOUT"));
      SPI.end();
      digitalWrite(PIN_RESET, HIGH);
      return false;
    }
  }

  setPointer(0x0000);
  return true;
}

void finish() {
  writeCSS(0x00, 0x00);
  SPI.transfer(0xff);
  SPI.transfer(0xff);
  digitalWrite(PIN_RESET, HIGH);
  delay(1);
  setProgrammingPinsHighImpedance();
}
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

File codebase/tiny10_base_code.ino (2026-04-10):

/**************************************************
   TPI programmer for ATtiny4/5/9/10/20/40

   Make the connections as shown below.

   To use:
 ***** Buad rate must be set to 9600 ****

    - Upload to arduino and power off
    - Connect ATtiny10 as shown
    - Power on and open the serial monitor
    - If things are working so far you should
      see "NVM enabled" and "ATtiny10/20/40 connected".
    - Input one-letter commands via serial monitor:

      D = dump memory. Displays all current memory
          on the chip

      E = erase chip. Erases all program memory
          automatically done at time of programming

      P = write program. After sending this, paste
          the program from the hex file into the
          serial monitor.

      S = set fuse. follow the instructions to set
          one of the three fuses.

      C = clear fuse. follow the instructions to clear
          one of the three fuses.

      L = Set Lock Bits No further programming & verification
          possible

      H = Toggle High Voltage Programming

      T = Toggle +12v enabled by High, or Low

      R/r = Quick reset

      I = Check the device ID

    - Finally, power off the arduino and remove the
      Attiny10/20/40


   Arduino                 ATtiny10
   ----------+          +----------------
   (SS#)  10 |--[R]-----| 6 (RESET#/PB3)
             |          |
   (MOSI) 11 |--[R]--+--| 1 (TPIDATA/PB0)
             |       |  |
   (MISO) 12 |--[R]--+  |
             |          |
   (SCK)  13 |--[R]-----| 3 (TPICLK/PB1)
   ----------+          +----------------
 *                                                *
   ----------+          +----------------
   (HVP)   9 |---       | 6 (RESET#/PB3)m
             |          |
 *                                                *
    -[R]-  =  a 220 - 1K Ohm resistor
 *                                                *
    this picture : 2011/12/08 by pcm1723
    modified :2015/02/27 by KD
 *                                                *
   thanks to pcm1723 for tpitest.pde upon which
   this is based
 **************************************************
  Updates:

   May 02, 2018: kimio.kosaka@gmail.com
                 Added 'I' command 

   Apr 02, 2018: Ksdsksd@gmail.com
                  Added Lock bit setting to main menu

   Jan 23, 2017: Ksdsksd@gmail.com
                  Thanks to InoueTaichi Fixed incorrect #define Tiny40

   Mar 05, 2015: Ksdsksd@gamil.com
                  Added notifications to setting and clearing the system flags.

   Feb 23, 2015: Ksdsksd@gamil.com
                  Changed the programmer Diagram, This is the config I use, and get a sucessful programming of a tiny10 at 9600 baud.

   Mar 22, 2014: Ksdsksd@gmail.com
                  Added the quick reset to high before resetting the device.
                  Added code to stop the SPI and float the pins for testing the device while connected.

   Mar 20, 2014: Ksdsksd@gmail.com
                  Added a quick reset by sending 'r' or 'R' via the serial monitor.
                  Added a High voltage programming option from pin 9, toggled by 'H'
                  Added a High/low option for providing 12v to the reset pin, toggled by 'T'

   Mar 17, 2014: Ksdsksd@gmail.com
                  Had some trouble with the nibbles being swapped when programming on the 10 & 20,
                  added b1,b2 to hold the serial data before calling byteval()
                  Added Nat Blundell's patch to the code

   Apr 10, 2013: Ksdsksd@gmail.com
                  Applied Fix for setting and clearing flags

   Feb 7,  2013: Ksdsksd@gmail.com
                  Fixed programming timer, had intitial start at zero instead of current time.

   Dec 11, 2012: Ksdsksd@gmail.com
                  Added detect and programming for 4/5/9

   Dec 5-6, 2012: Ksdsksd@gmail.com
                  Incorperated read, and verify into program. Now have no program size limitation by using 328p.
                  Changed the outHex routines consolidated them into 1, number to be printed, and number of nibbles
                  Added a type check to distinguish between Tiny10/20/40
                  Added an auto word size check to ensure that there is the proper amount of words written for a 10/20/40
                  Removed Read program, Verify, and Finish from options
                  Changed baud rate to 19200 for delay from data written to the chip, to prevent serial buffer overrun.

   Oct 5, 2012: Ksdsksd@gmail.com
                *** Noticed that when programming, the verification fails
                    at times by last 1-2 bytes programmed, and the Tiny would act erratic.
                    Quick fix was adding 3 NOP's to the end the Tiny's code, and ignoring the errors, the Tiny then performed as expected.

   Oct 4, 2012: Ksdsksd@gmail.com
                  Moved all Serial printed strings to program space
                  Added code to detect Tiny20
*/

#include <SPI.h>
#include "pins_arduino.h"

// define the instruction set bytes
#define SLD    0x20
#define SLDp   0x24
#define SST    0x60
#define SSTp   0x64
#define SSTPRH 0x69
#define SSTPRL 0x68
// see functions below ////////////////////////////////
// SIN  0b0aa1aaaa replace a with 6 address bits
// SOUT 0b1aa1aaaa replace a with 6 address bits
// SLDCS  0b1000aaaa replace a with address bits
// SSTCS  0b1100aaaa replace a with address bits
///////////////////////////////////////////////////////
#define SKEY   0xE0
#define NVM_PROGRAM_ENABLE 0x1289AB45CDD888FFULL // the ULL means unsigned long long

#define NVMCMD 0x33
#define NVMCSR 0x32
#define NVM_NOP 0x00
#define NVM_CHIP_ERASE 0x10
#define NVM_SECTION_ERASE 0x14
#define NVM_WORD_WRITE 0x1D

#define HVReset 9

#define Tiny4_5 10
#define Tiny9 1
#define Tiny10 1
#define Tiny20 2
#define Tiny40 4

#define TimeOut 1
#define HexError 2
#define TooLarge 3
// represents the current pointer register value
unsigned short adrs = 0x0000;

// used for storing a program file
uint8_t data[16]; //program data
unsigned int progSize = 0; //program size in bytes

// used for various purposes
long startTime;
int timeout;
uint8_t b, b1, b2, b3;
boolean idChecked;
boolean correct;
char type; // type of chip connected 1 = Tiny10, 2 = Tiny20
char HVP = 0;
char HVON = 0;

void setup() {
  // set up serial
  Serial.begin(9600); // you cant increase this, it'll overrun the buffer
  // set up SPI
  /*  SPI.begin();
    SPI.setBitOrder(LSBFIRST);
    SPI.setDataMode(SPI_MODE0);
    SPI.setClockDivider(SPI_CLOCK_DIV32);

  */  start_tpi();


  pinMode(HVReset, OUTPUT);
  // initialize memory pointer register
  setPointer(0x0000);

  timeout = 20000;
  idChecked = false;
} // end setup()


void hvserial()
{
  if (HVP)
    Serial.println(F("***High Voltage Programming Enabled***"));
  else
    Serial.println(F("High Voltage Programming Disabled"));

  Serial.print(F("Pin 9 "));
  Serial.print(HVON ? F("HIGH") : F("LOW"));
  Serial.print(F(" supplies 12v"));

}
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

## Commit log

2026-04-10 First Commit!
    [MouseMinder-B_Cu.gbr, MouseMinder-B_Mask.gbr, MouseMinder-B_Paste.gbr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]
2026-04-12 First commit baby!
    [000_Boss-Extrude11[15].step, 001_Boss-Extrude11[4].step, 002_Boss-Extrude11[14].step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]
2026-04-12 nuked my old repo. inadvertantely removed all old files. Made a backup, restoring backup
    [000_Boss-Extrude11[15].step, 001_Boss-Extrude11[4].step, 002_Boss-Extrude11[14].step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]
2026-04-12 Gui tweaks. Added in some pass-fail logic and am still working on the clear memory command and read metadata command
    [ardu_tiny_toaster.ino, gui.py]
2026-08-16 I had to modify the freePDK firmware and programmer PCB to get the pogo jig to work. Very happy with this code.
2026-10-04 Update PCB pushbutton 3D model
2026-10-12 Rev 6.1 turned a resistor 90 degrees for rework, updated the silkscreen.
2026-10-12 Updated MPNs for tighter tolerance (100 ohms), older name-brand stock (caps), and tape-and-reel battery holder to reduce mfg cost
